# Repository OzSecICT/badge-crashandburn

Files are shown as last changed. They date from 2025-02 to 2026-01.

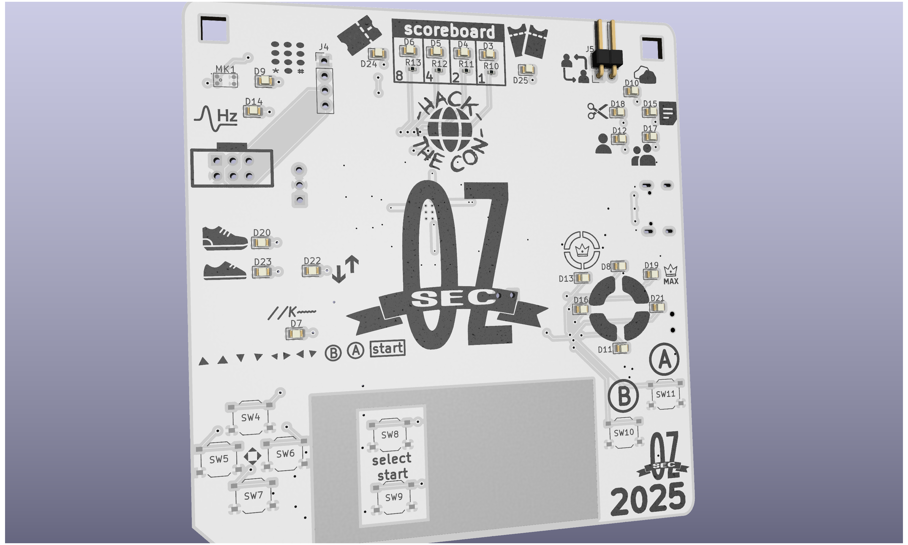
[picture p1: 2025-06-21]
hardware/kicad/OzSec2025-ESP32/images/Rendering_White.png

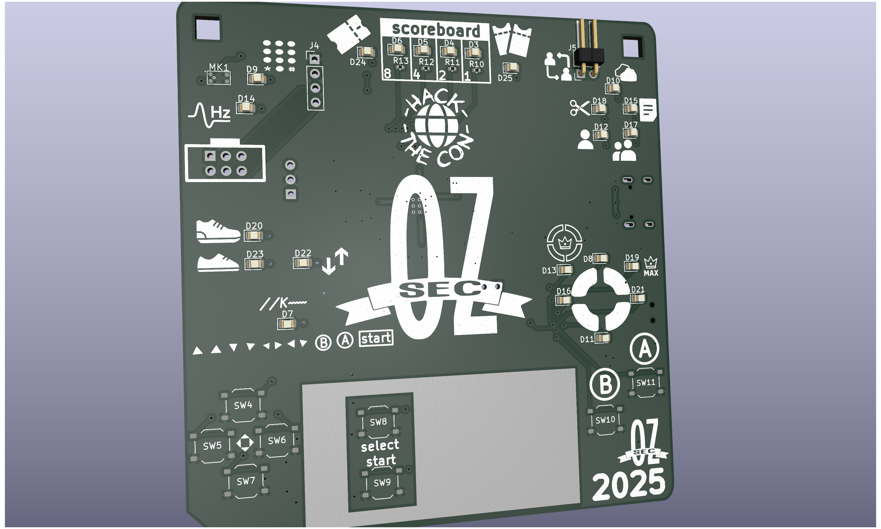
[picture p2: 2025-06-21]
hardware/kicad/OzSec2025-ESP32/images/Rendering_Green.png

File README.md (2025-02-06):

# OzSec 2025 Badge: CRASHANDBURN
This is the git repo for the code and supporting documents for the OzSec 2025 badge, codename CRASHANDBURN.

This badge will be built in MicroPython on an RP2040 or RP2350, and support multiple minigames.

This repo is currently a work in progress as we start planning how to lay out the badge firmware.

## Contributing
You will need a few things to help develop the badge firmware:
- Visual Studio Code
- VS Code Extensions: Python, Pylance
- Python 3.12+
- mpremote 1.24+

Install Python, and then install `mpremote`. Install VS Code, and clone this repository. Open the repo in VS Code and install the recommended extensions.

Currently the badge firmware is developed with a Raspberry Pi Pico 2 on a breadboard. If you want to see the code, obtain one and follow these steps to get it setup:
- Plug in drive while holding BOOTSEL and use the flash script or VS Code Task to flash firmware. 
    - In VS Code, hit Ctrl+Shift+P or Cmd+Shift+P and choose `Tasks: Run Task` followed by `Flash MicroPython Firmware`.
- After you make changes to the code, hit Ctrl+Shift+B or Cmd+Shift+B to automatically upload the code and reset the device.

## Folder Structure
`.vscode` has the needed VS Code settings for recommended plugins, tasks, and settings for Pylance.

`firmware` has the MicroPython firmware, so everyone uses the same one.

`scripts` contains supporting scripts, such as flash and upload scripts. These are used by VS Code Tasks.

`source` is the MicroPython source files uploaded to the device.

`typings` contains Python typings for MicroPython. It stops the red squigglies.

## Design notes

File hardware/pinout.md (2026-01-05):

# Pinout
Below pinout is for ESP32 version.

## LEDs
Badge Complete = GPIO2
Badge Bonus = GPIO4

Score 1s = GPIO5
Score 2s = GPIO6
Score 4s = GPIO7
Score 8s = GPIO15

RPS Complete = GPIO8
RPS Rock = GPIO16
RPS Paper = GPIO17
RPS Scissors = GPIO18

Simon Complete = GPIO46
Simon Up = GPIO3
Simon Right = GPIO9
Simon Left = GPIO11
Simon Down = GPIO10

DTMF Complete = GPIO43
DTMF Bonus = GPIO44

HiLo Complete = GPIO40
HiLo Hi = GPIO42
HiLo Lo = GPIO41

Kode Complete = GPIO39

## Buttons
Up = GPIO38
Right = GPIO47
Left = GPIO45
Down = GPIO48

Select = GPIO14
Start = GPIO21

A = GPIO12
B = GPIO13

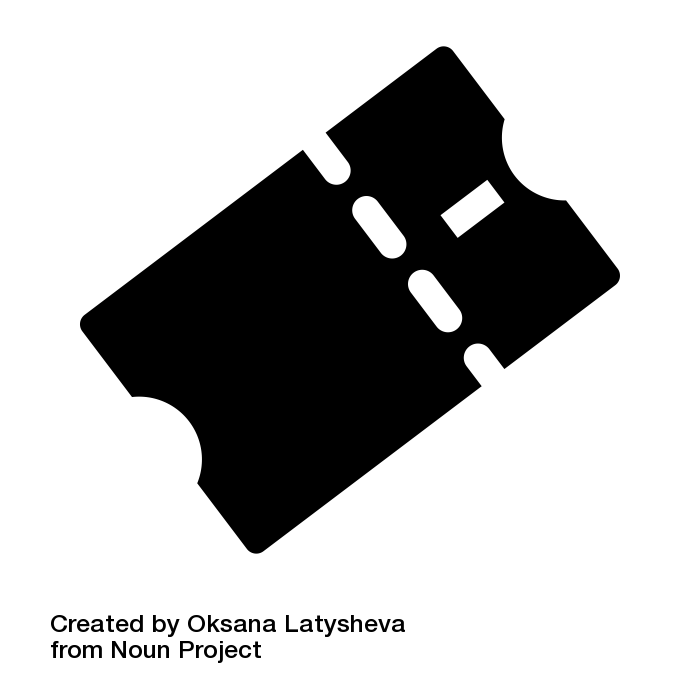
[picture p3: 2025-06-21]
hardware/kicad/OzSec2025-ESP32/images/raffle.png

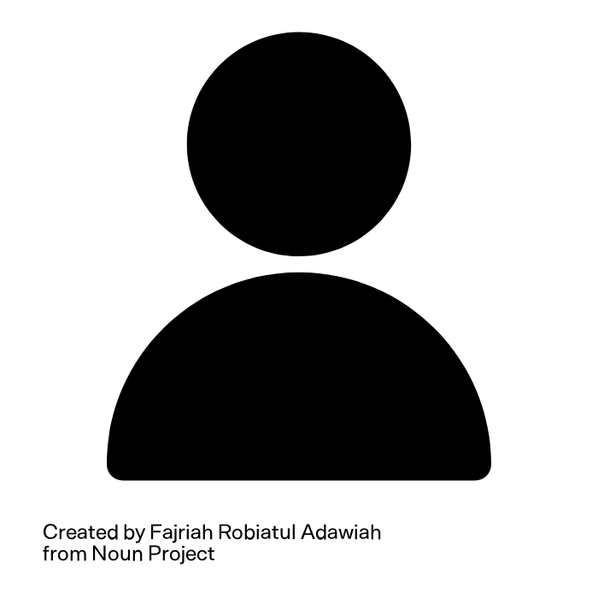
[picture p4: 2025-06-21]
hardware/kicad/OzSec2025-ESP32/images/rps-single.png

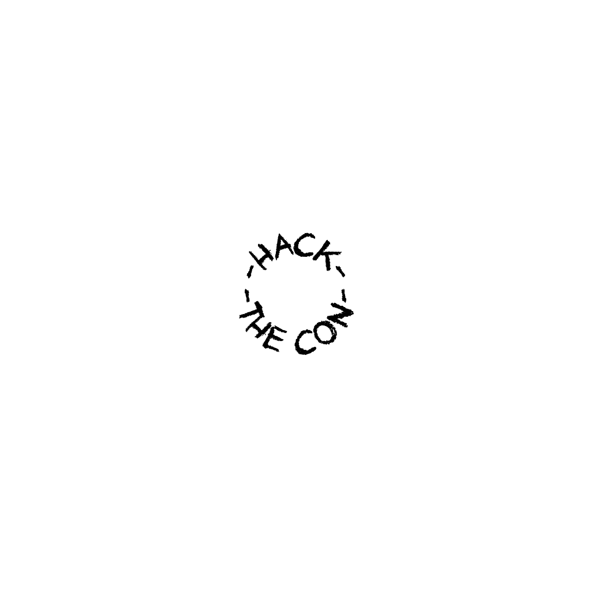
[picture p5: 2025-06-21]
hardware/kicad/OzSec2025-ESP32/images/hackthecon.png

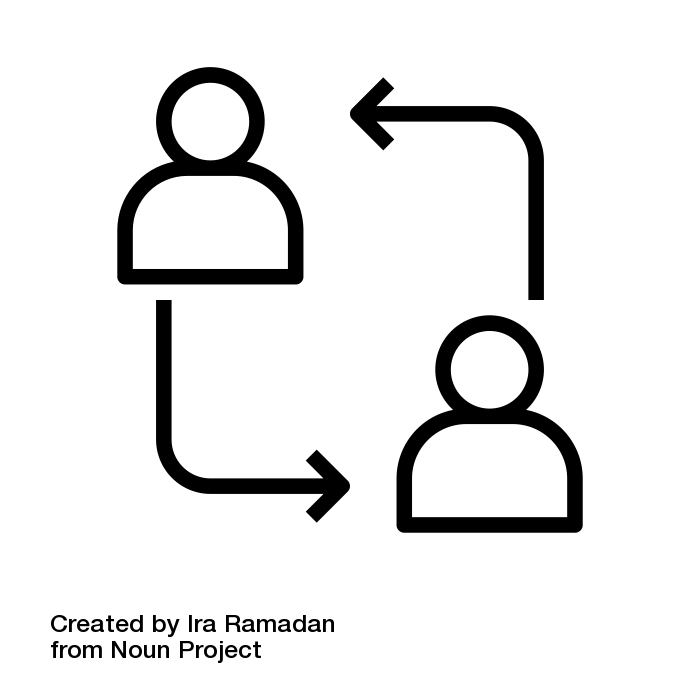
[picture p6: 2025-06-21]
hardware/kicad/OzSec2025-ESP32/images/RPS_Link.png

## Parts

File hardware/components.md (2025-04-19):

# Component Bill of Materials

This is the current planned/work in progress bill of materials.

https://jlcpcb.com/partdetail/Waveshare-1_8inch_LCDModule/C359940 - round
https://jlcpcb.com/partdetail/C42370667 / https://www.waveshare.com/1.28inch-touch-lcd.htm - new, round with touch

https://jlcpcb.com/partdetail/Hs-HS96L03W2C03/C5248080 - small square
https://jlcpcb.com/partdetail/Newvisio-N087_2832TSWYG02H14/C2890610 - small rectangle

## TODO
Update 1k resistors to 0402 like the Crystal
Update footprint of controller buttons, currently using the reset/boot buttons.
Add jtag header
add uart header
add gpio headers

## USB Connector
USB-C Connector: [C2988369](https://jlcpcb.com/partdetail/gswitch-GT_USB7010ASV/C2988369)
ESD Protection: [C2827654](https://jlcpcb.com/partdetail/TechPublic-USBLC62SC6/C2827654)
USB-C 5.1k resistors x2: [C27834](https://jlcpcb.com/partdetail/26648-0402WGF5101TCE/C25905)

## Charge Controller
Controller: C478383
Capacitor 1uF: C52923
Resistors 2k x2: C17604
Fuse: C261957
Power Switch: C431541
AA Connectors x2: C2979179
Charge LED Yellow: C2296

## Voltage Regulator
Regulator: C15578
Capcitor 1uF: C1525
Capcitor 100uF: C15008
LED resistor 1k: C17513
LED green: C2297

## RP Crystal
Crystal: C20625731 $0.1980
Resistor 1k: C17513 $0.0017
Capacitor 15pF 2x: C1644 $0.0045

## RP Flash
Chip: C97521 $0.3375
Capacitor 100nF: C1525 $0.0010
Resistor 0ohm: C17168 $0.0005

## RP2350
Chip: C42415655 $1.1760
Resistor 27ohm x2: C138021 $0.0006
Reset and boot switches: C318884 $0.0146
resistor 33ohm: C25105 $0.0005
resistor 1k x2: C17513 $0.0017
capacitor 100nF x11: C307331 $0.0052
capacitor 4.7uF x4: C23733 $0.0050
Inductor: C42411119 $0.1967

ESP32-S3-WROOM-1-N8R8: $3.92
RP2350 and friends: $1.82
CH32V003F4U6: $0.1863

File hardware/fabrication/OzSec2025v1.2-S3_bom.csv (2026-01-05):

Designator | Footprint | Quantity | Value | LCSC Part #
BATTERY | MY-AA-04_Silkscreen_Only | 1 | Battery | C2979179
BT1 | MY-AA-04 | 1 | Battery_Clip_+ | C2979179
BT3 | MY-AA-04 | 1 | Battery_Clip_- | C2979179
C1 | 0805 | 1 | 22uF | C45783
C2, C4 | 0805 | 2 | 100nF | C49678
C3 | 0805 | 1 | 10uF | C15850
C5 | 1206 | 1 | 100uF | C15008
C6 | 0805 | 1 | 1uF | C28323
D1, D13, D19, D6 | 0805 | 4 | GREEN | C2297
D10, D11, D12, D14, D15, D16, D17, D18, D2, D3, D4, D5, D7, D8, D9 | 0805 | 15 | WHITE | C34499
D20, D23 | 0805 | 2 | YELLOW | C2296
D21 | 0805 | 1 | RED | C84256
D22 | 0805 | 1 | BLUE | C2293
F1 | 1206 | 1 | Fuse | C261957
J1 | USB_C_Receptacle_G-Switch_GT-USB-7010ASV | 1 | USB_C_Receptacle_USB2.0 | C2988369
MK1 | LMA3722T421-OA5 | 1 | LMA3722T421-OA5 | C5373233
R1, R10, R12, R13, R14, R15, R16, R17, R18, R19, R2, R20, R21, R22, R23, R24, R25, R26, R3, R4, R5, R6, R9 | 0805 | 23 | 1K | C17513
R11 | 0805 | 1 | 10K | C17414
R27 | 0805 | 1 | 2K | C17604
R7, R8 | 0805 | 2 | 5.1K | C27834
SW1 | SW_SPDT_PCM12 | 1 | SPDT | C431541
SW10, SW11, SW2, SW3, SW4, SW5, SW6, SW7, SW8, SW9 | SW_Push_1P1T_XKB_TS-1187A | 10 | SW_Push | C318884
U1 | SOT-23-6 | 1 | USBLC6-2SC6 | C2827654
U2 | SOT-223-3_TabPin2 | 1 | TLV1117LV-33 | C15578
U3 | ESP32-S3-WROOM-1 | 1 | ESP32-S3-WROOM-1-N8R8 | C2913201
U4 | TSOT-23-5 | 1 | ME4054BM5G-N | C478383
X1 | Simple_Addon_v2-BADGE-2x3 | 1 | Simple_Addon_v2 | C2935983

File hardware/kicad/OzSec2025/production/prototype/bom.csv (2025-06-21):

Designator | Footprint | Quantity | Value | LCSC Part #
BT1 | MY-AA-04_BT1A | 1 | Battery_Clip_+
BT2 | MY-AA-04 | 1 | Battery | C2979179
BT3 | MY-AA-04_BT1B | 1 | Battery_Clip_-
C1, C12, C13, C14, C15, C16, C17, C18, C19, C20, C21, C22, C9 | 0402 | 13 | 100n | C1525
C10, C11, C7, C8 | 0402 | 4 | 4.7u | C23733
C2, C3 | 0402 | 2 | 15p | C1548
C4 | 0805 | 1 | 10u | C15850
C5 | 1206 | 1 | 100uF | C15008
C6 | 0402 | 1 | 1uF | C52923
D1 | 0805 | 1 | YELLOW | C2296
D10, D11, D12, D13, D14, D15, D16, D17, D18, D19, D20, D21, D22, D23, D24, D25, D3, D4, D5, D6, D7, D8, D9 | 0805 | 23 | WHITE | C34499
D2 | 0805 | 1 | GREEN | C2297
F1 | 1206 | 1 | Fuse | C261957
J1 | USB_C_Receptacle_G-Switch_GT-USB-7010ASV | 1 | USB_C_Receptacle_USB2.0 | C2988369
J5 | PinHeader_1x02_P2.54mm_Horizontal | 1 | Conn_01x02 | C492410
L1 | L_pol_2016 | 1 | 3.3u | C42411119
MK1 | LMA3722T421-OA5 | 1 | LMA3722T421-OA5 | C5373233
R1 | 0402 | 1 | 2K | C4109
R10, R11, R12, R13, R16, R17, R18, R19, R2, R20, R21, R22, R23, R24, R25, R26, R27, R28, R29, R3, R30, R31, R32, R33, R34, R4, R7, R9 | 0402 | 28 | 1K | C11702
R14, R15 | 0402 | 2 | 27 | C25100
R5, R6 | 0402 | 2 | 5.1K | C25905
R8 | 0402 | 1 | 33 | C25105
SW1 | SW_SPDT_PCM12 | 1 | POWER | C431541
SW10, SW11, SW2, SW3, SW4, SW5, SW6, SW7, SW8, SW9 | SW_Push_1P1T_XKB_TS-1187A | 10 | SW_Push | C318884
TP1, TP3 | TestPoint_Pad_1.5x1.5mm | 2 | TestPoint
TP2, TP4 | TestPoint_Pad_D1.5mm | 2 | TestPoint
U1 | SOT-223-3_TabPin2 | 1 | TLV1117LV-33 | C15578
U2 | SOT-23-6 | 1 | USBLC6-2SC6 | C2827654
U3 | TSOT-23-5 | 1 | ME4054BM5G-N | C478383
U4 | RP2350-QFN-80-1EP_10x10_P0.4mm_EP3.4x3.4mm_ThermalVias | 1 | RP2350_80QFN | C42415655
U5 | SOIC-8_5.23x5.23mm_P1.27mm | 1 | W25Q128JVS | C97521
X1 | Simple_Addon_v2-BADGE-2x3 | 1 | Simple_Addon_v2 | C2935983
Y1 | Crystal_SMD_3225-4Pin_3.2x2.5mm | 1 | ABM8-272-T3 | C20625731

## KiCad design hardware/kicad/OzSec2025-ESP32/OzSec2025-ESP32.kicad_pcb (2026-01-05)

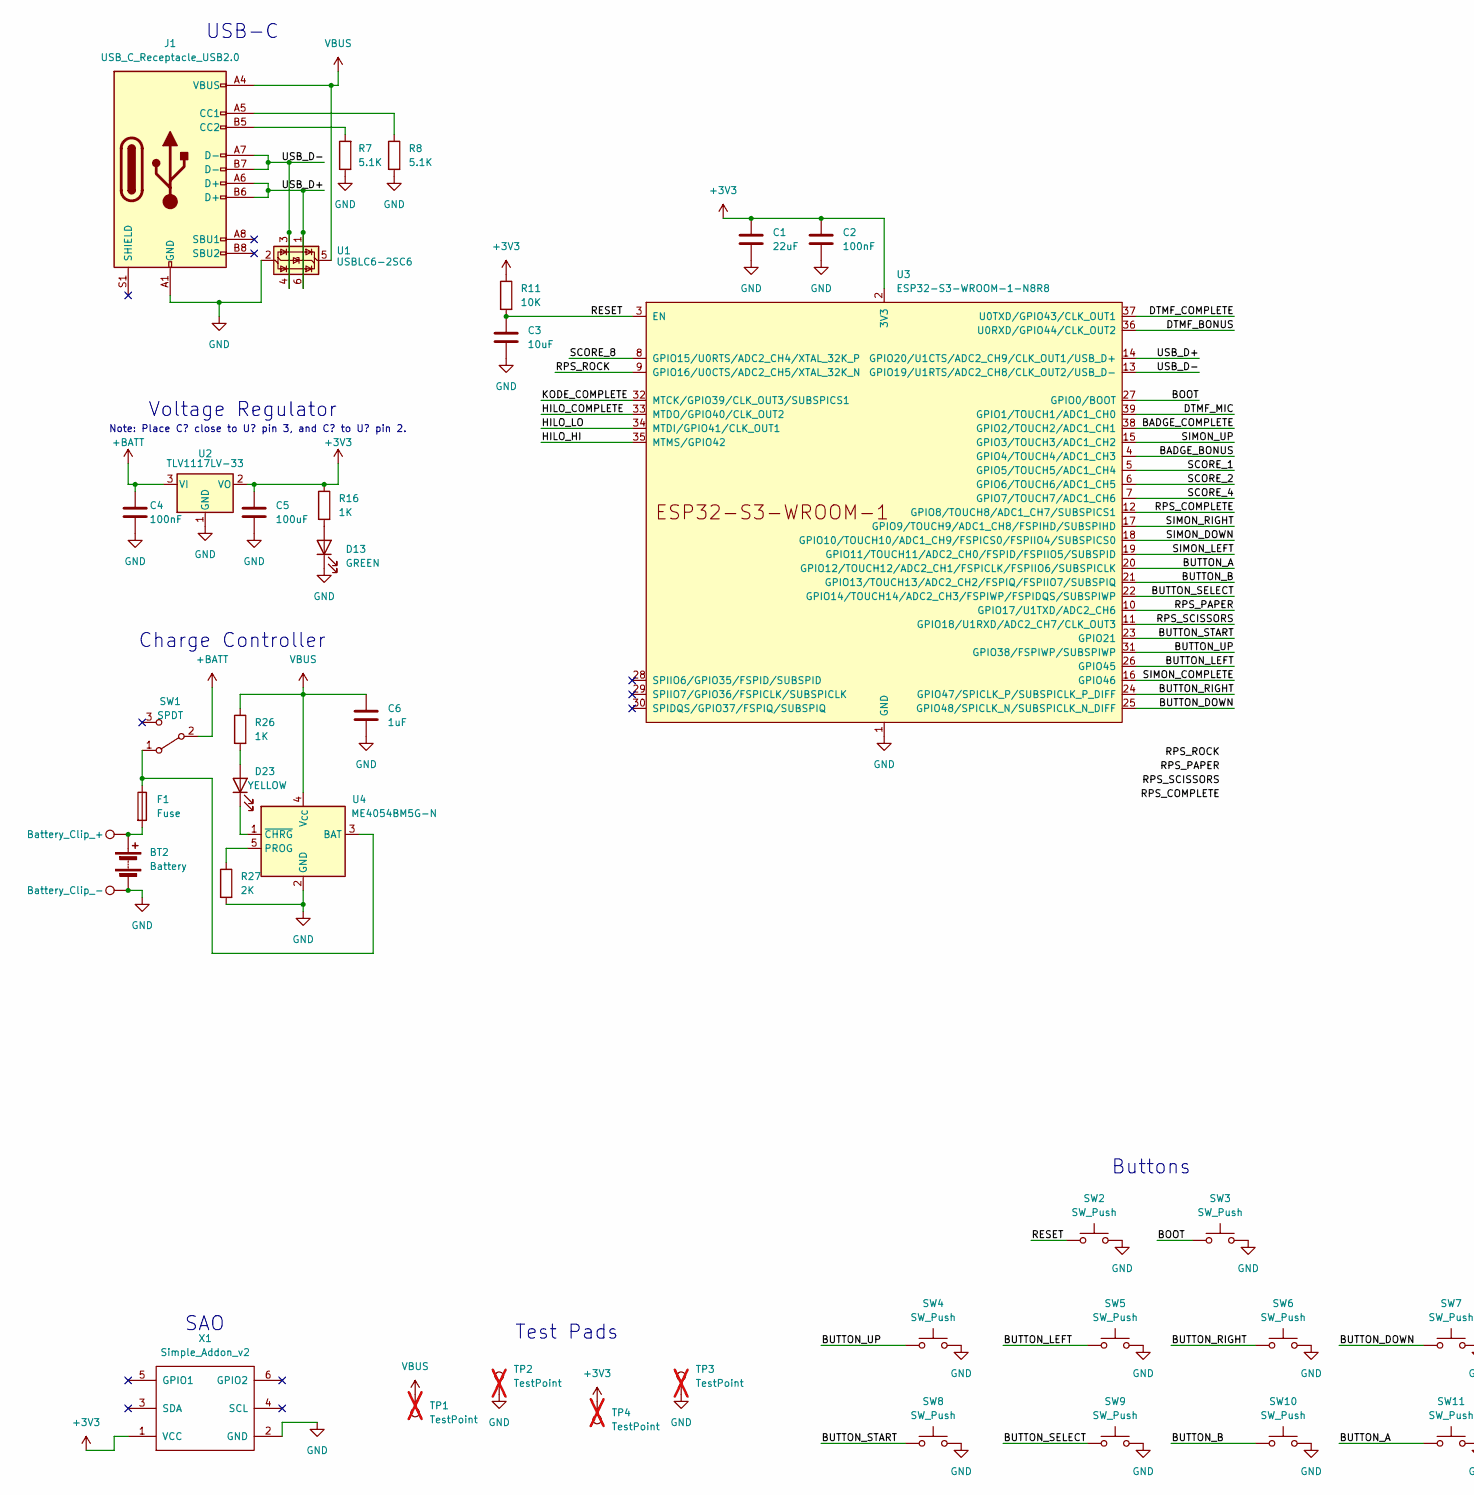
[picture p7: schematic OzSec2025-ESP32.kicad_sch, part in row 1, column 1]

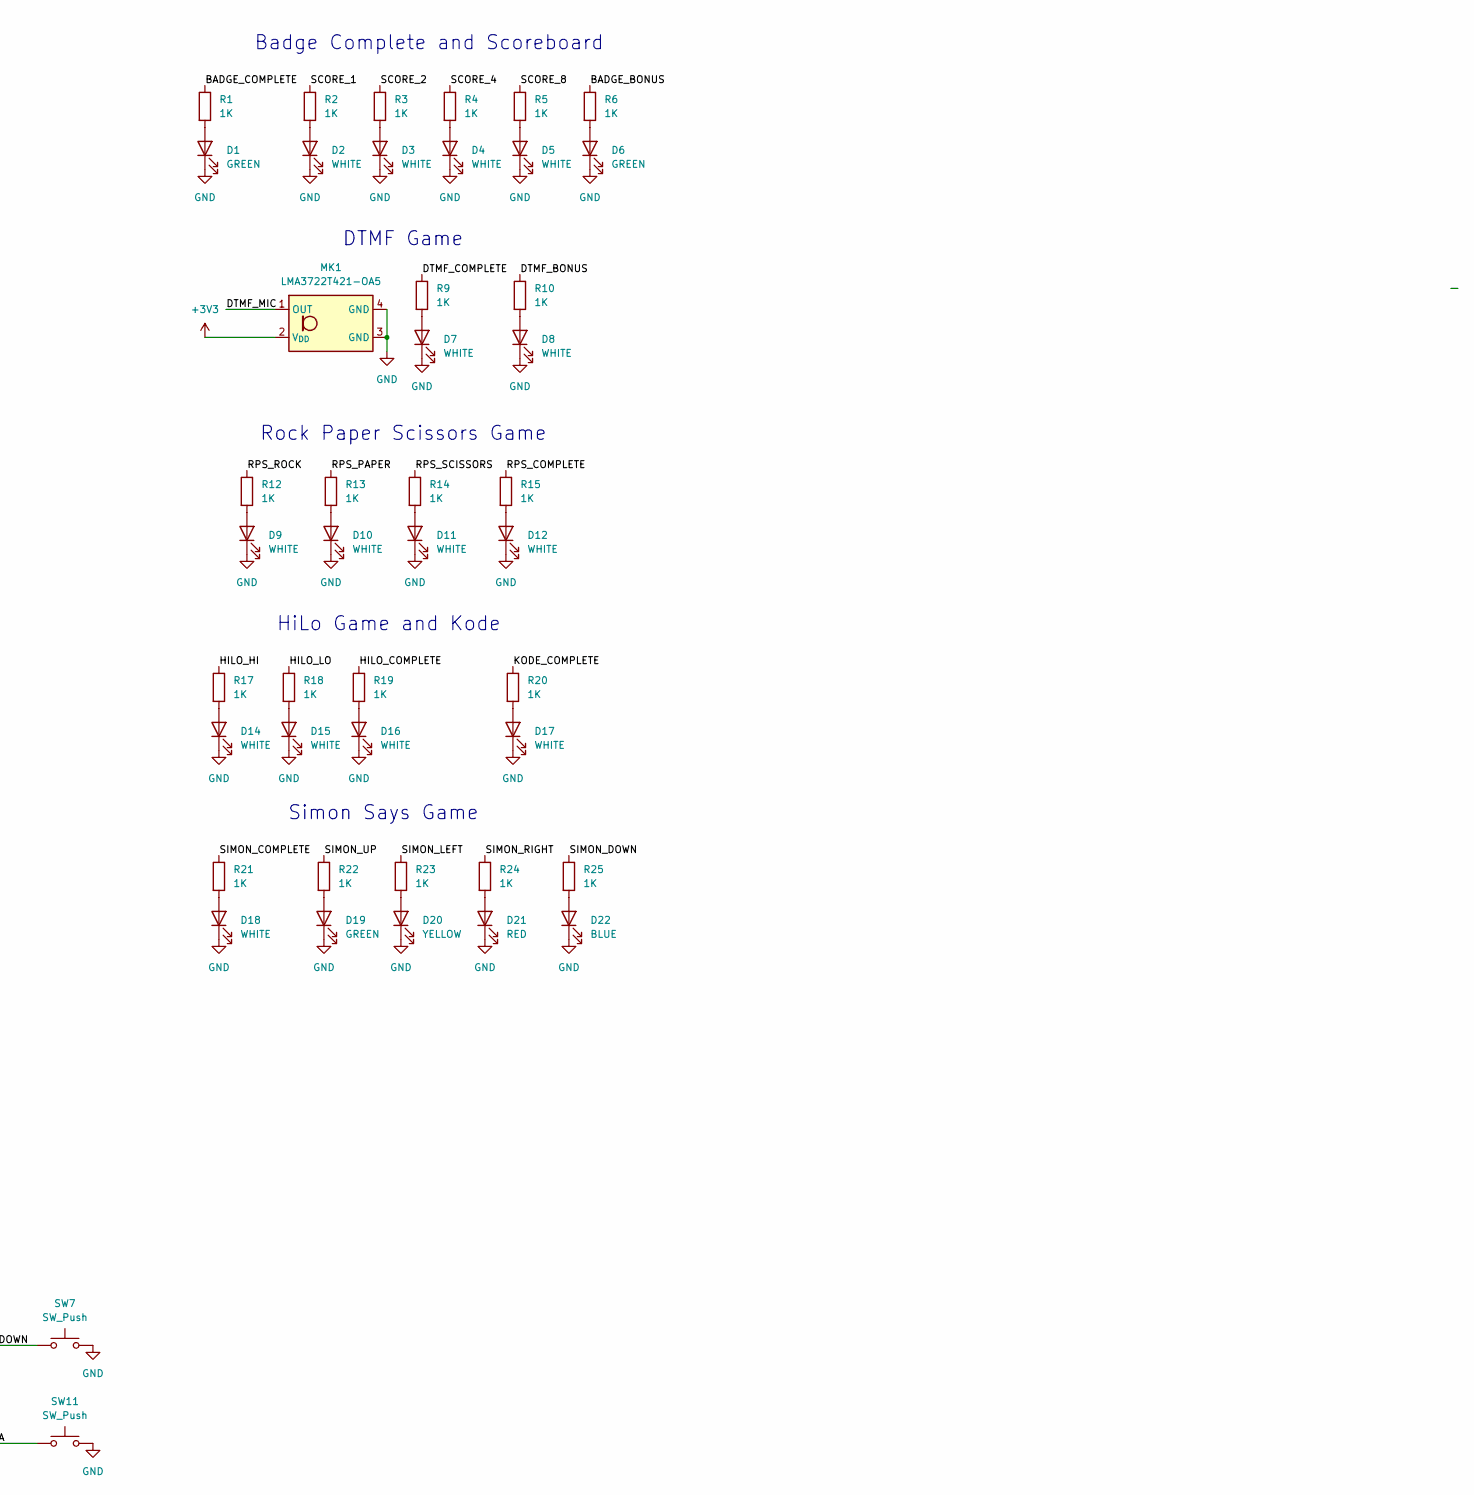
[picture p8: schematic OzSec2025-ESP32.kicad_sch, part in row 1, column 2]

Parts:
BT1: Battery_Clip_+; MY-AA-04; LCSC C2979179
BT2: Battery; MY-AA-04; LCSC C2979179
BT3: Battery_Clip_-; MY-AA-04; LCSC C2979179
C1: 22uF; C_0805_2012Metric_Pad1.18x1.45mm_HandSolder; LCSC C45783
C2, C4: 100nF; C_0805_2012Metric_Pad1.18x1.45mm_HandSolder; LCSC C49678
C3: 10uF; C_0805_2012Metric_Pad1.18x1.45mm_HandSolder; LCSC C15850
C5: 100uF; C_1206_3216Metric_Pad1.33x1.80mm_HandSolder; LCSC C15008
C6: 1uF; C_0805_2012Metric_Pad1.18x1.45mm_HandSolder; LCSC C28323
D1, D6, D13, D19: GREEN; LED_0805_2012Metric_Pad1.15x1.40mm_HandSolder; LCSC C2297
D2, D3, D4, D5, D7, D8, D9, D10, D11, D12, D14, D15, D16, D17, D18: WHITE; LED_0805_2012Metric_Pad1.15x1.40mm_HandSolder; LCSC C34499
D20, D23: YELLOW; LED_0805_2012Metric_Pad1.15x1.40mm_HandSolder; LCSC C2296
D21: RED; LED_0805_2012Metric_Pad1.15x1.40mm_HandSolder; LCSC C84256
D22: BLUE; LED_0805_2012Metric_Pad1.15x1.40mm_HandSolder; LCSC C2293
F1: Fuse; Fuse_1206_3216Metric_Pad1.42x1.75mm_HandSolder; LCSC C261957
J1: USB_C_Receptacle_USB2.0; USB_C_Receptacle_G-Switch_GT-USB-7010ASV; LCSC C2988369
MK1: LMA3722T421-OA5; LCSC C5373233
R1, R2, R3, R4, R5, R6, R9, R10, R12, R13, R14, R15, R16, R17, R18, R19, R20, R21, R22, R23, R24, R25, R26: 1K; R_0805_2012Metric_Pad1.20x1.40mm_HandSolder; LCSC C17513
R7, R8: 5.1K; R_0805_2012Metric_Pad1.20x1.40mm_HandSolder; LCSC C27834
R11: 10K; R_0805_2012Metric_Pad1.20x1.40mm_HandSolder; LCSC C17414
R27: 2K; R_0805_2012Metric_Pad1.20x1.40mm_HandSolder; LCSC C17604
SW1: SPDT; SW_SPDT_PCM12; LCSC C431541
SW2, SW3, SW4, SW5, SW6, SW7, SW8, SW9, SW10, SW11: SW_Push; SW_Push_1P1T_XKB_TS-1187A; LCSC C318884
TP1, TP4: TestPoint; TestPoint_Pad_1.5x1.5mm; not fitted
TP2, TP3: TestPoint; TestPoint_Pad_D1.5mm; not fitted
U1: USBLC6-2SC6; SOT-23-6; LCSC C2827654
U2: TLV1117LV-33; SOT-223-3_TabPin2; LCSC C15578
U3: ESP32-S3-WROOM-1-N8R8; ESP32-S3-WROOM-1; LCSC C2913201
U4: ME4054BM5G-N; TSOT-23-5; LCSC C478383
X1: Simple_Addon_v2; Simple_Addon_v2-BADGE-2x3; LCSC C2935983

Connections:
+3V3: C1.1, C2.1, C5.1, MK1.2 (V_{DD}), R11.1, R16.1, TP4.1, U2.2 (VO), U3.2 (3V3), X1.1 (VCC)
+BATT: C4.1, SW1.2 (B), U2.3 (VI)
/BADGE_BONUS: R6.1, U3.4 (GPIO4/TOUCH4/ADC1_CH3)
/BADGE_COMPLETE: R1.1, U3.38 (GPIO2/TOUCH2/ADC1_CH1)
/BOOT: SW3.1, U3.27 (GPIO0/BOOT)
/BUTTON_A: SW11.1, U3.20 (GPIO12/TOUCH12/ADC2_CH1/FSPICLK/FSPIIO6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)
/BUTTON_B: SW10.1, U3.21 (GPIO13/TOUCH13/ADC2_CH2/FSPIQ/FSPIIO7/S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)
/BUTTON_DOWN: SW7.1, U3.25 (GPIO48/SPICLK_N/SUBSPICLK_N_DIFF)
/BUTTON_LEFT: SW5.1, U3.26 (GPIO45)
/BUTTON_RIGHT: SW6.1, U3.24 (GPIO47/SPICLK_P/SUBSPICLK_P_DIFF)
/BUTTON_SELECT: SW9.1, U3.22 (GPIO14/TOUCH14/ADC2_CH3/FSPIWP/FSPIDQS/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)
/BUTTON_START: SW8.1, U3.23 (GPIO21)
/BUTTON_UP: SW4.1, U3.31 (GPIO38/FSPIWP/SUBSPIWP)
/DTMF_BONUS: R10.1, U3.36 (U0RXD/GPIO44/CLK_OUT2)
/DTMF_COMPLETE: R9.1, U3.37 (U0TXD/GPIO43/CLK_OUT1)
/DTMF_MIC: MK1.1 (OUT), U3.39 (GPIO1/TOUCH1/ADC1_CH0)
/HILO_COMPLETE: R19.1, U3.33 (MTDO/GPIO40/CLK_OUT2)
/HILO_HI: R17.1, U3.35 (MTMS/GPIO42)
/HILO_LO: R18.1, U3.34 (MTDI/GPIO41/CLK_OUT1)
/KODE_COMPLETE: R20.1, U3.32 (MTCK/GPIO39/CLK_OUT3/SUBSPICS1)
/RESET: C3.1, R11.2, SW2.1, U3.3 (EN)
/RPS_COMPLETE: R15.1, U3.12 (GPIO8/TOUCH8/ADC1_CH7/SUBSPICS1)
/RPS_PAPER: R13.1, U3.10 (GPIO17/U1TXD/ADC2_CH6)
/RPS_ROCK: R12.1, U3.9 (GPIO16/U0CTS/ADC2_CH5/XTAL_32K_N)
/RPS_SCISSORS: R14.1, U3.11 (GPIO18/U1RXD/ADC2_CH7/CLK_OUT3)
/SCORE_1: R2.1, U3.5 (GPIO5/TOUCH5/ADC1_CH4)
/SCORE_2: R3.1, U3.6 (GPIO6/TOUCH6/ADC1_CH5)
/SCORE_4: R4.1, U3.7 (GPIO7/TOUCH7/ADC1_CH6)
/SCORE_8: R5.1, U3.8 (GPIO15/U0RTS/ADC2_CH4/XTAL_32K_P)
/SIMON_COMPLETE: R21.1, U3.16 (GPIO46)
/SIMON_DOWN: R25.1, U3.18 (GPIO10/TOUCH10/ADC1_CH9/FSPICS0/FSPIIO4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)
/SIMON_LEFT: R23.1, U3.19 (GPIO11/TOUCH11/ADC2_CH0/FSPID/FSPIIO5/S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)
/SIMON_RIGHT: R24.1, U3.17 (GPIO9/TOUCH9/ADC1_CH8/FSPIHD/SUBSPIHD)
/SIMON_UP: R22.1, U3.15 (GPIO3/TOUCH3/ADC1_CH2)
/USB_D+: J1.A6 (D+), J1.B6 (D+), U1.1 (I/O1), U1.6 (I/O1), U3.14 (GPIO20/U1CTS/ADC2_CH9/CLK_OUT1/USB_D+)
/USB_D-: J1.A7 (D-), J1.B7 (D-), U1.3 (I/O2), U1.4 (I/O2), U3.13 (GPIO19/U1RTS/ADC2_CH8/CLK_OUT2/USB_D-)
GND: BT1.2, BT3.1, C1.2, C2.2, C3.2, C4.2, C5.2, C6.2, D1.1 (K), D2.1 (K), D3.1 (K), D4.1 (K), D5.1 (K), D6.1 (K), D7.1 (K), D8.1 (K), D9.1 (K), D10.1 (K), D11.1 (K), D12.1 (K), D13.1 (K), D14.1 (K), D15.1 (K), D16.1 (K), D17.1 (K), D18.1 (K), D19.1 (K), D20.1 (K), D21.1 (K), D22.1 (K), J1.A1 (GND), J1.A12 (GND), J1.B1 (GND), J1.B12 (GND), MK1.3 (GND), MK1.4 (GND), R7.1, R8.2, R27.2, SW2.2, SW3.2, SW4.2, SW5.2, SW6.2, SW7.2, SW8.2, SW9.2, SW10.2, SW11.2, TP2.1, TP3.1, U1.2 (GND), U2.1 (GND), U3.1 (GND), U3.40 (GND), U3.41 (GND), U4.2 (GND), X1.2 (GND)
unnamed: BT1.1, F1.2
unnamed: D1.2 (A), R1.2
unnamed: D2.2 (A), R2.2
unnamed: D3.2 (A), R3.2
unnamed: D4.2 (A), R4.2
unnamed: D5.2 (A), R5.2
unnamed: D6.2 (A), R6.2
unnamed: D7.2 (A), R9.2
unnamed: D8.2 (A), R10.2
unnamed: D9.2 (A), R12.2
unnamed: D10.2 (A), R13.2
unnamed: D11.2 (A), R14.2
unnamed: D12.2 (A), R15.2
unnamed: D13.2 (A), R16.2
unnamed: D14.2 (A), R17.2
unnamed: D15.2 (A), R18.2
unnamed: D16.2 (A), R19.2
unnamed: D17.2 (A), R20.2
unnamed: D18.2 (A), R21.2
unnamed: D19.2 (A), R22.2
unnamed: D20.2 (A), R23.2
unnamed: D21.2 (A), R24.2
unnamed: D22.2 (A), R25.2
unnamed: D23.2 (A), R26.2
unnamed: D23.1 (K), U4.1 (~CHRG)
unnamed: J1.A5 (CC1), R8.1
unnamed: J1.B5 (CC2), R7.2
unnamed: F1.1, SW1.1 (A), U4.3 (BAT)
unnamed: R27.1, U4.5 (PROG)
VBUS: C6.1, J1.A4 (VBUS), J1.A9 (VBUS), J1.B4 (VBUS), J1.B9 (VBUS), R26.1, TP1.1, U1.5 (VBUS), U4.4 (V_{CC})

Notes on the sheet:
USB-C
Charge Controller
Badge Complete and Scoreboard
Test Pads
DTMF Game
Voltage Regulator
SAO
HiLo Game and Kode
Note: Place C? close to U? pin 3, and C? to U? pin 2.
Buttons
Simon Says Game
Rock Paper Scissors Game

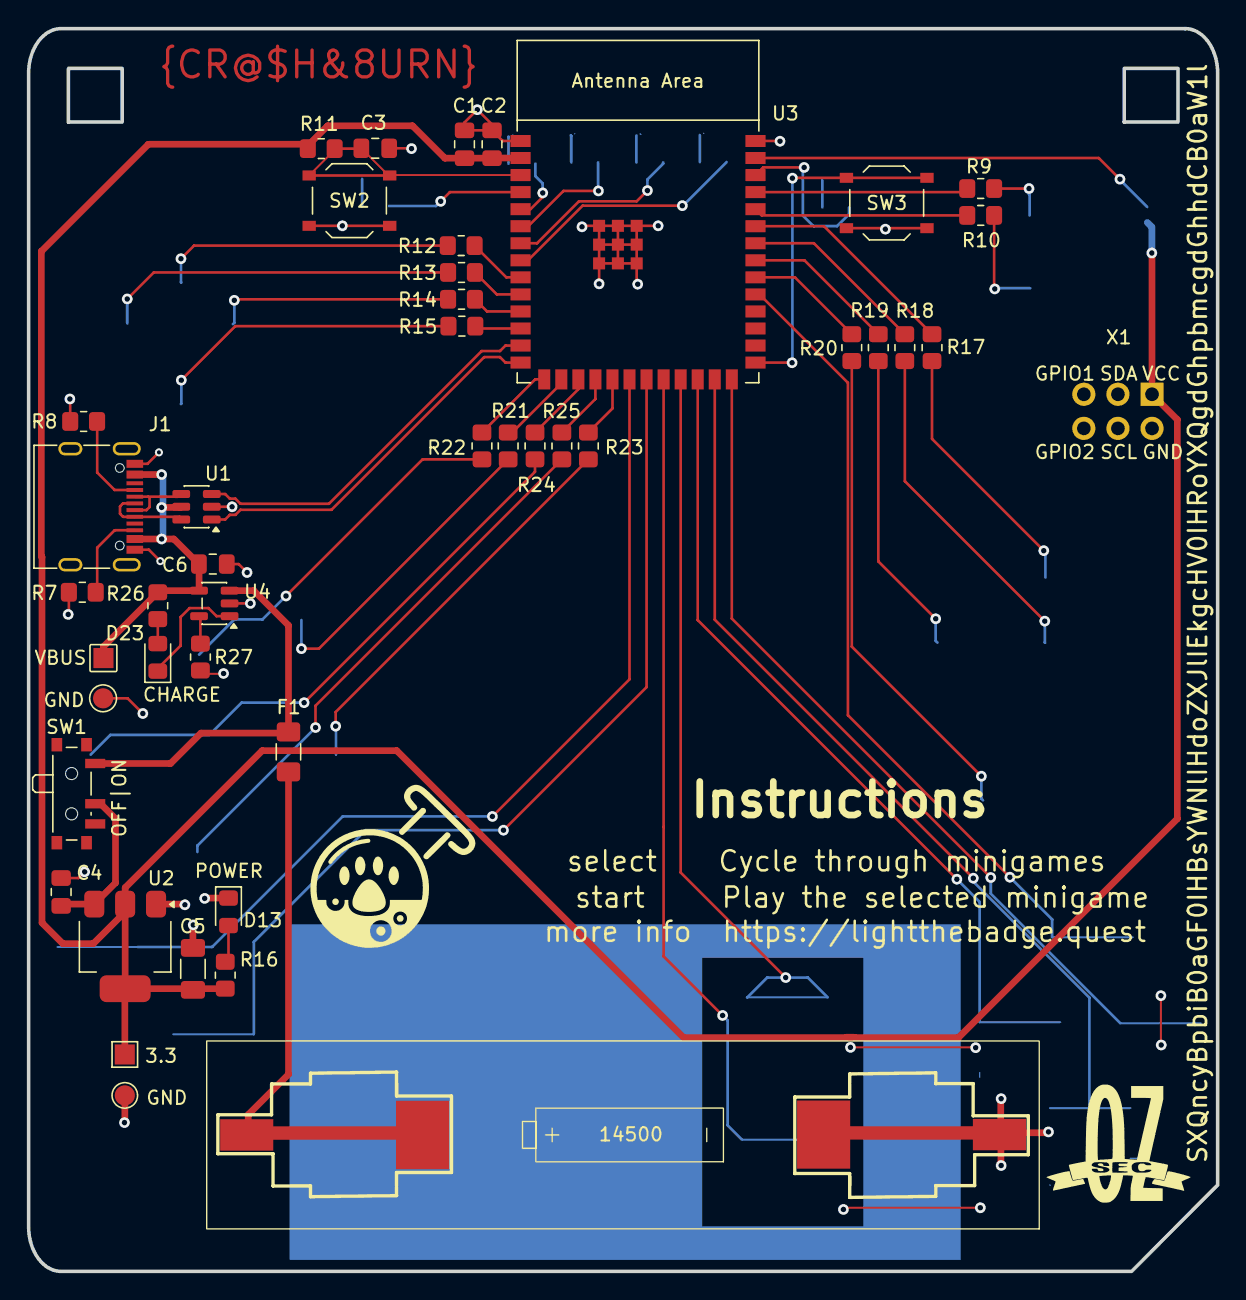
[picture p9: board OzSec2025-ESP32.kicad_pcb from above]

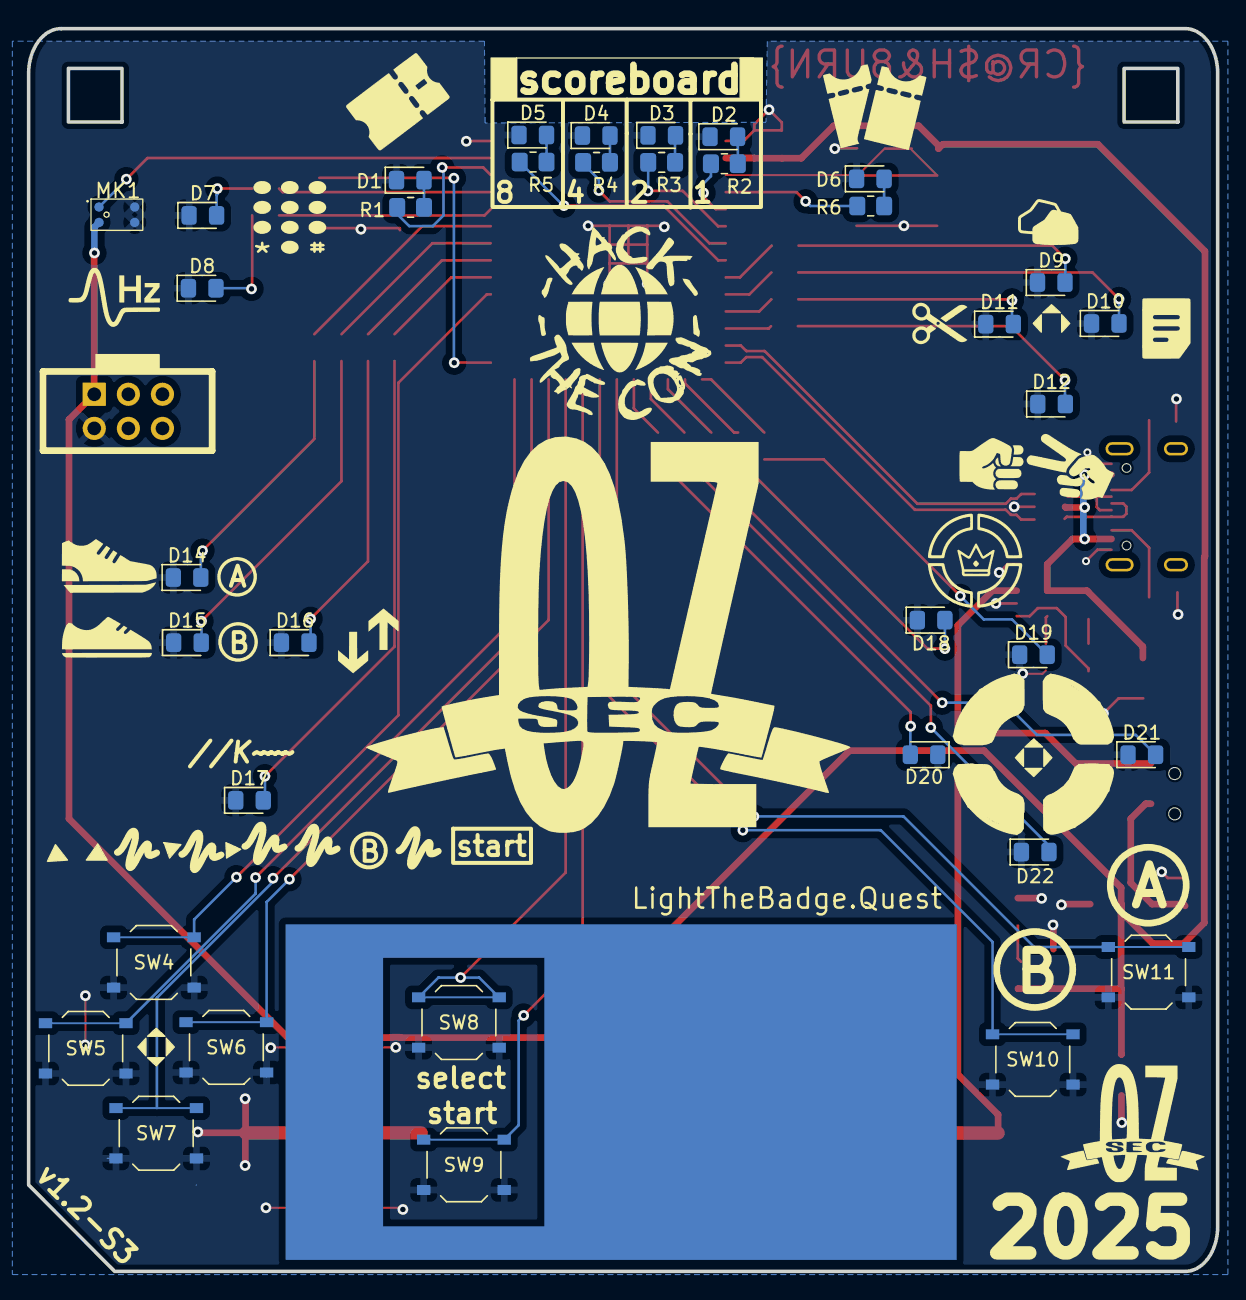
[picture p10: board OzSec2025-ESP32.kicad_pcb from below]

Board: 2 copper layers, 88.6 x 92.6 mm, 82 parts (37 on the bottom side), 67 nets.

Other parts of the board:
BATTERY: Battery; MY-AA-04_Silkscreen_Only

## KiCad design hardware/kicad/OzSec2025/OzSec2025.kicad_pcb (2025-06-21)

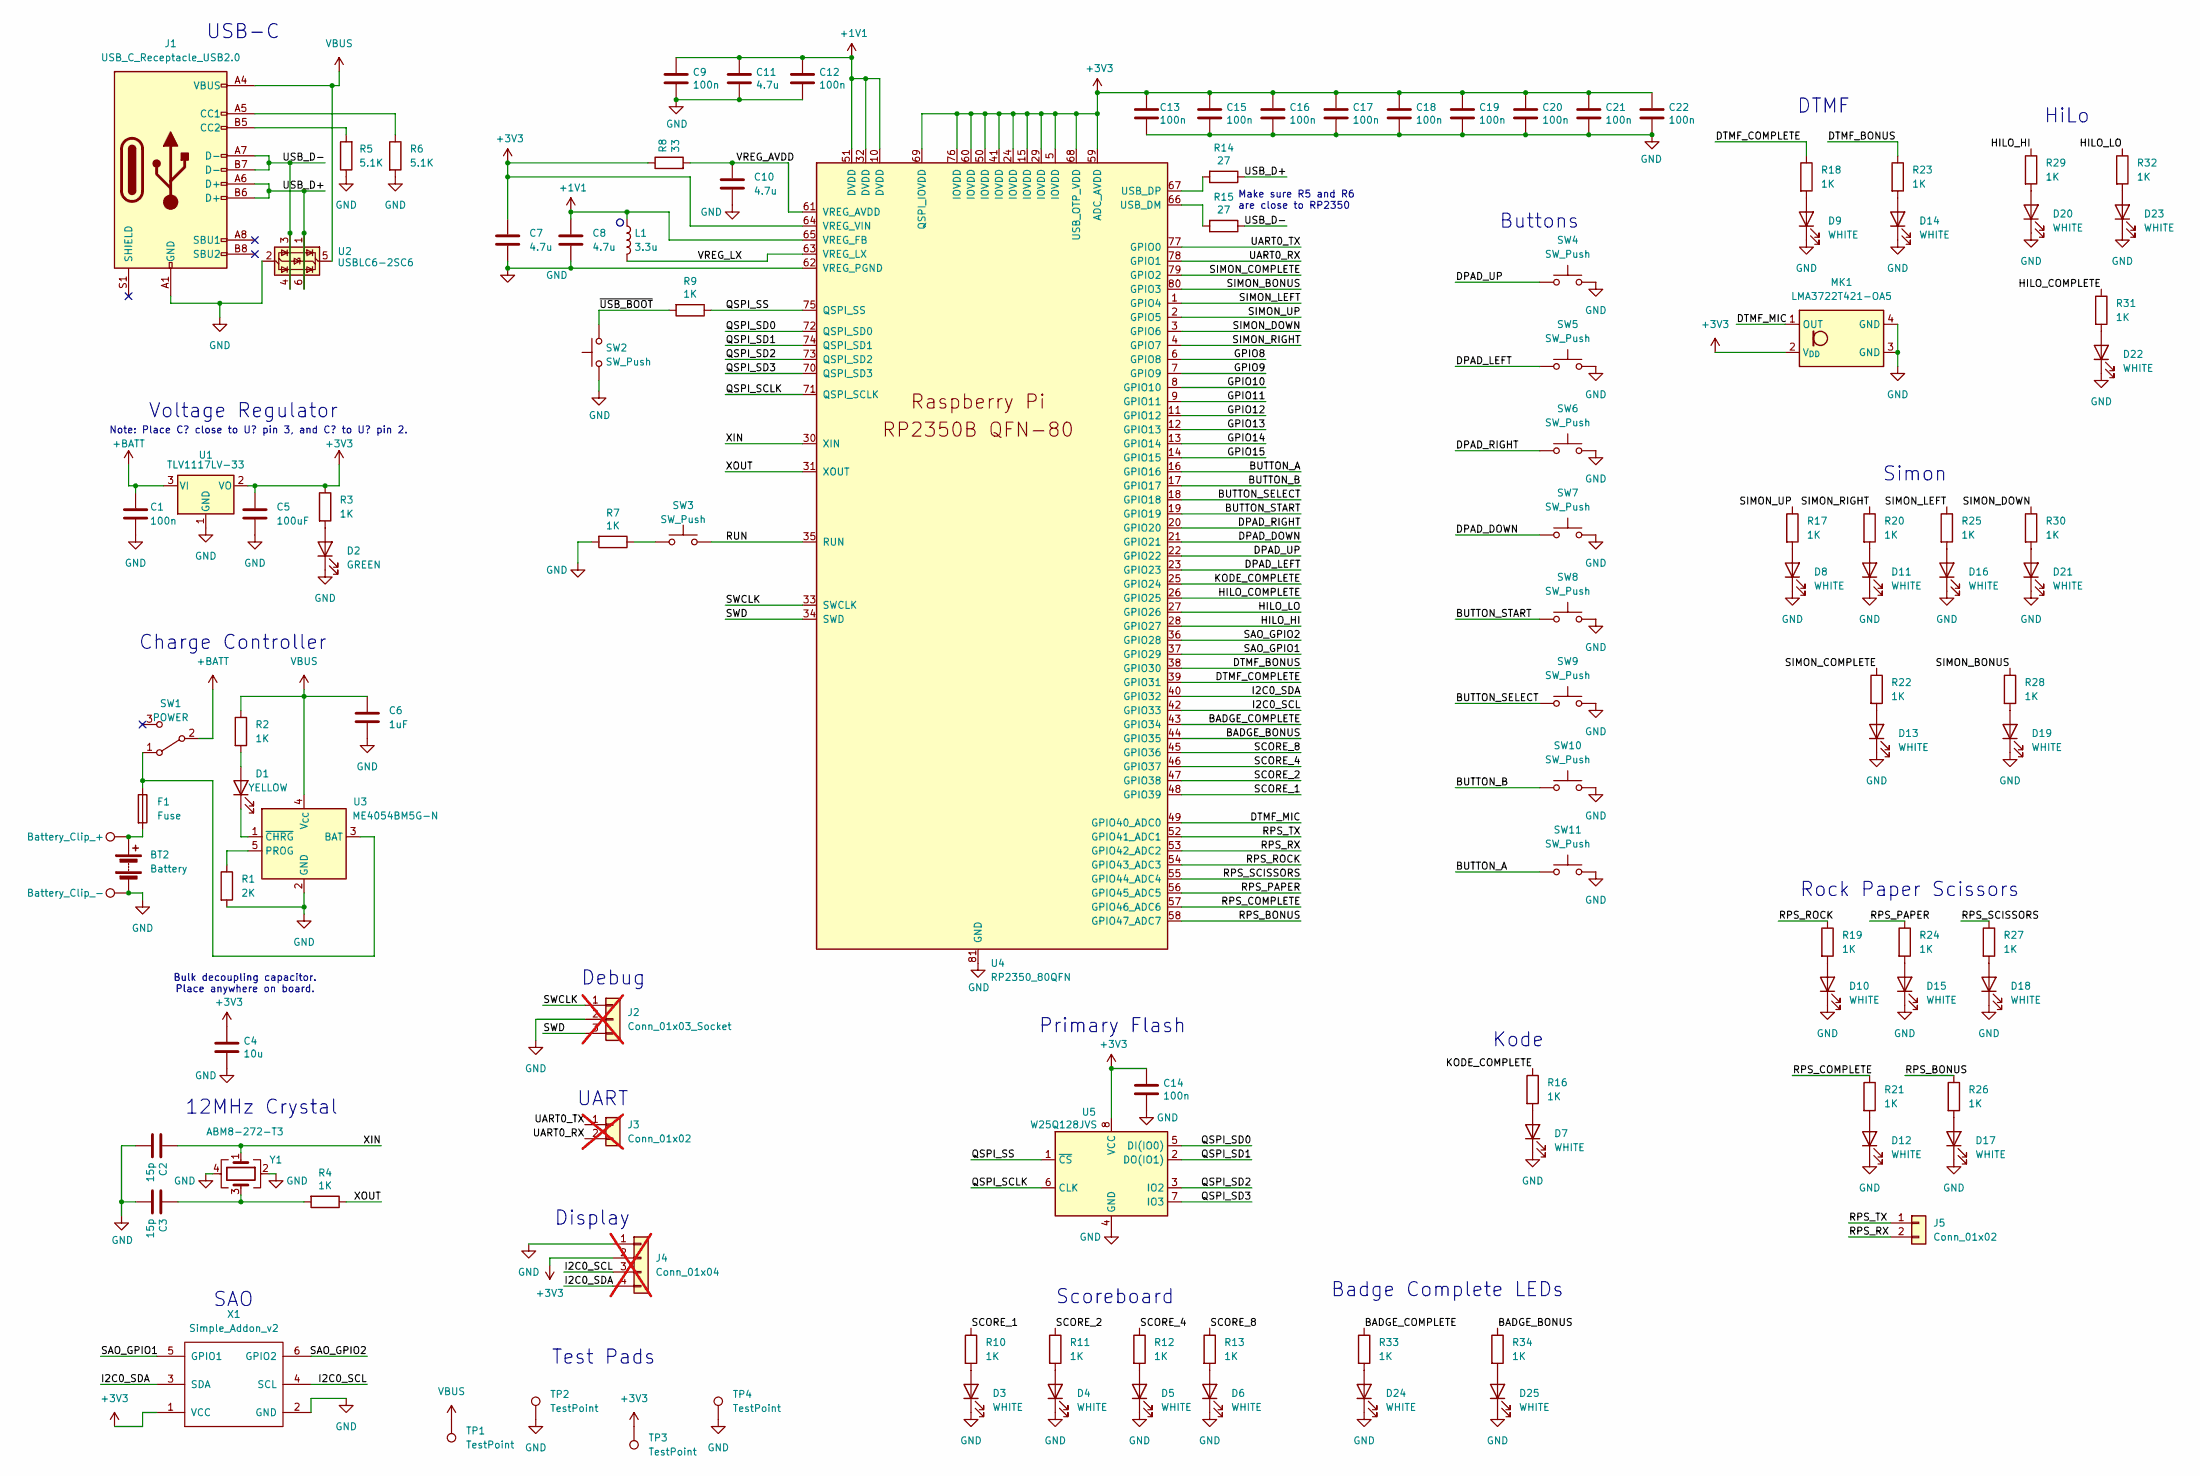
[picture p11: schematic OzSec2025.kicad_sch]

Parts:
BT1: Battery_Clip_+; MY-AA-04_BT1A
BT2: Battery; MY-AA-04; LCSC C2979179
BT3: Battery_Clip_-; MY-AA-04_BT1B
C1, C9, C12, C13, C14, C15, C16, C17, C18, C19, C20, C21, C22: 100n; C_0402_1005Metric; LCSC C1525
C2, C3: 15p; C_0402_1005Metric; LCSC C1548
C4: 10u; C_0805_2012Metric; LCSC C15850
C5: 100uF; C_1206_3216Metric; LCSC C15008
C6: 1uF; C_0402_1005Metric; LCSC C52923
C7, C8: 4.7u; C_0402_1005Metric_small_pads; LCSC C23733
C10, C11: 4.7u; C_0402_1005Metric; LCSC C23733
D1: YELLOW; LED_0805_2012Metric; LCSC C2296
D2: GREEN; LED_0805_2012Metric; LCSC C2297
D3, D4, D5, D6, D7, D8, D9, D10, D11, D12, D13, D14, D15, D16, D17, D18, D19, D20, D21, D22, D23, D24, D25: WHITE; LED_0805_2012Metric; LCSC C34499
F1: Fuse; Fuse_1206_3216Metric; LCSC C261957
J1: USB_C_Receptacle_USB2.0; USB_C_Receptacle_G-Switch_GT-USB-7010ASV; LCSC C2988369
J2: Conn_01x03_Socket; PinHeader_1x03_P2.54mm_Vertical; not fitted
J3: Conn_01x02; PinHeader_1x02_P2.54mm_Vertical; not fitted
J4: Conn_01x04; PinHeader_1x04_P2.54mm_Vertical; not fitted
J5: Conn_01x02; PinHeader_1x02_P2.54mm_Horizontal; LCSC C492410
L1: 3.3u; L_pol_2016; LCSC C42411119
MK1: LMA3722T421-OA5; LCSC C5373233
R1: 2K; R_0402_1005Metric; LCSC C4109
R2, R3, R4, R7, R9, R10, R11, R12, R13, R16, R17, R18, R19, R20, R21, R22, R23, R24, R25, R26, R27, R28, R29, R30, R31, R32, R33, R34: 1K; R_0402_1005Metric; LCSC C11702
R5, R6: 5.1K; R_0402_1005Metric; LCSC C25905
R8: 33; R_0402_1005Metric; LCSC C25105
R14, R15: 27; R_0402_1005Metric; LCSC C25100
SW1: POWER; SW_SPDT_PCM12; LCSC C431541
SW2, SW3, SW4, SW5, SW6, SW7, SW8, SW9, SW10, SW11: SW_Push; SW_Push_1P1T_XKB_TS-1187A; LCSC C318884
TP1, TP3: TestPoint; TestPoint_Pad_1.5x1.5mm
TP2, TP4: TestPoint; TestPoint_Pad_D1.5mm
U1: TLV1117LV-33; SOT-223-3_TabPin2; LCSC C15578
U2: USBLC6-2SC6; SOT-23-6; LCSC C2827654
U3: ME4054BM5G-N; TSOT-23-5; LCSC C478383
U4: RP2350_80QFN; RP2350-QFN-80-1EP_10x10_P0.4mm_EP3.4x3.4mm_ThermalVias; LCSC C42415655
U5: W25Q128JVS; SOIC-8_5.23x5.23mm_P1.27mm; LCSC C97521
X1: Simple_Addon_v2; Simple_Addon_v2-BADGE-2x3; LCSC C2935983
Y1: ABM8-272-T3; Crystal_SMD_3225-4Pin_3.2x2.5mm; LCSC C20625731

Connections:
+1V1: C8.1, C9.1, C11.1, C12.1, L1.1, U4.10 (DVDD), U4.32 (DVDD), U4.51 (DVDD), U4.65 (VREG_FB)
+3V3: C4.1, C5.1, C7.1, C13.1, C14.1, C15.1, C16.1, C17.1, C18.1, C19.1, C20.1, C21.1, C22.1, J4.2, MK1.2 (V_{DD}), R3.1, R8.1, TP3.1, U1.2 (VO), U4.5 (IOVDD), U4.15 (IOVDD), U4.24 (IOVDD), U4.29 (IOVDD), U4.41 (IOVDD), U4.50 (IOVDD), U4.59 (ADC_AVDD), U4.60 (IOVDD), U4.64 (VREG_VIN), U4.68 (USB_OTP_VDD), U4.69 (QSPI_IOVDD), U4.76 (IOVDD), U5.8 (VCC), X1.1 (VCC)
+BATT: C1.1, SW1.2 (B), U1.3 (VI)
/BADGE_BONUS: R34.1, U4.44 (GPIO35)
/BADGE_COMPLETE: R33.1, U4.43 (GPIO34)
/BUTTON_A: SW11.1, U4.16 (GPIO16)
/BUTTON_B: SW10.1, U4.17 (GPIO17)
/BUTTON_SELECT: SW9.1, U4.18 (GPIO18)
/BUTTON_START: SW8.1, U4.19 (GPIO19)
/DPAD_DOWN: SW7.1, U4.21 (GPIO21)
/DPAD_LEFT: SW5.1, U4.23 (GPIO23)
/DPAD_RIGHT: SW6.1, U4.20 (GPIO20)
/DPAD_UP: SW4.1, U4.22 (GPIO22)
/DTMF_BONUS: R23.1, U4.38 (GPIO30)
/DTMF_COMPLETE: R18.1, U4.39 (GPIO31)
/DTMF_MIC: MK1.1 (OUT), U4.49 (GPIO40_ADC0)
/GPIO8: U4.6 (GPIO8)
/GPIO9: U4.7 (GPIO9)
/GPIO10: U4.8 (GPIO10)
/GPIO11: U4.9 (GPIO11)
/GPIO12: U4.11 (GPIO12)
/GPIO13: U4.12 (GPIO13)
/GPIO14: U4.13 (GPIO14)
/GPIO15: U4.14 (GPIO15)
/HILO_COMPLETE: R31.1, U4.26 (GPIO25)
/HILO_HI: R29.1, U4.28 (GPIO27)
/HILO_LO: R32.1, U4.27 (GPIO26)
/I2C0_SCL: J4.3, U4.42 (GPIO33), X1.4 (SCL)
/I2C0_SDA: J4.4, U4.40 (GPIO32), X1.3 (SDA)
/KODE_COMPLETE: R16.1, U4.25 (GPIO24)
/QSPI_SCLK: U4.71 (QSPI_SCLK), U5.6 (CLK)
/QSPI_SD0: U4.72 (QSPI_SD0), U5.5 (DI(IO0))
/QSPI_SD1: U4.74 (QSPI_SD1), U5.2 (DO(IO1))
/QSPI_SD2: U4.73 (QSPI_SD2), U5.3 (IO2)
/QSPI_SD3: U4.70 (QSPI_SD3), U5.7 (IO3)
/QSPI_SS: R9.1, U4.75 (QSPI_SS), U5.1 (~CS)
/RPS_BONUS: R26.1, U4.58 (GPIO47_ADC7)
/RPS_COMPLETE: R21.1, U4.57 (GPIO46_ADC6)
/RPS_PAPER: R24.1, U4.56 (GPIO45_ADC5)
/RPS_ROCK: R19.1, U4.54 (GPIO43_ADC3)
/RPS_RX: J5.2, U4.53 (GPIO42_ADC2)
/RPS_SCISSORS: R27.1, U4.55 (GPIO44_ADC4)
/RPS_TX: J5.1, U4.52 (GPIO41_ADC1)
/RUN: SW3.2, U4.35 (RUN)
/SAO_GPIO1: U4.37 (GPIO29), X1.5 (GPIO1)
/SAO_GPIO2: U4.36 (GPIO28), X1.6 (GPIO2)
/SCORE_1: R10.1, U4.48 (GPIO39)
/SCORE_2: R11.1, U4.47 (GPIO38)
/SCORE_4: R12.1, U4.46 (GPIO37)
/SCORE_8: R13.1, U4.45 (GPIO36)
/SIMON_BONUS: R28.1, U4.80 (GPIO3)
/SIMON_COMPLETE: R22.1, U4.79 (GPIO2)
/SIMON_DOWN: R30.1, U4.3 (GPIO6)
/SIMON_LEFT: R25.1, U4.1 (GPIO4)
/SIMON_RIGHT: R20.1, U4.4 (GPIO7)
/SIMON_UP: R17.1, U4.2 (GPIO5)
/SWCLK: J2.1, U4.33 (SWCLK)
/SWD: J2.3, U4.34 (SWD)
/UART0_RX: J3.2, U4.78 (GPIO1)
/UART0_TX: J3.1, U4.77 (GPIO0)
/USB_D+: J1.A6 (D+), J1.B6 (D+), R14.1, U2.1 (I/O1), U2.6 (I/O1)
/USB_D-: J1.A7 (D-), J1.B7 (D-), R15.1, U2.3 (I/O2), U2.4 (I/O2)
/VREG_AVDD: C10.1, R8.2, U4.61 (VREG_AVDD)
/VREG_LX: L1.2, U4.63 (VREG_LX)
/XIN: C2.1, U4.30 (XIN), Y1.1
/XOUT: R4.1, U4.31 (XOUT)
/~USB_BOOT: R9.2, SW2.2
GND: BT2.2 (-), BT3.1, C1.2, C2.2, C3.2, C4.2, C5.2, C6.2, C7.2, C8.2, C9.2, C10.2, C11.2, C12.2, C13.2, C14.2, C15.2, C16.2, C17.2, C18.2, C19.2, C20.2, C21.2, C22.2, D2.1 (K), D3.1 (K), D4.1 (K), D5.1 (K), D6.1 (K), D7.1 (K), D8.1 (K), D9.1 (K), D10.1 (K), D11.1 (K), D12.1 (K), D13.1 (K), D14.1 (K), D15.1 (K), D16.1 (K), D17.1 (K), D18.1 (K), D19.1 (K), D20.1 (K), D21.1 (K), D22.1 (K), D23.1 (K), D24.1 (K), D25.1 (K), J1.A1 (GND), J1.A12 (GND), J1.B1 (GND), J1.B12 (GND), J2.2, J4.1, MK1.3 (GND), MK1.4 (GND), R1.2, R5.1, R6.2, R7.2, SW2.1, SW4.2, SW5.2, SW6.2, SW7.2, SW8.2, SW9.2, SW10.2, SW11.2, TP2.1, TP4.1, U1.1 (GND), U2.2 (GND), U3.2 (GND), U4.62 (VREG_PGND), U4.81 (GND), U5.4 (GND), X1.2 (GND), Y1.2, Y1.4
unnamed: BT1.1, BT2.1 (+), F1.2
unnamed: C3.1, R4.2, Y1.3
unnamed: D1.2 (A), R2.2
unnamed: D1.1 (K), U3.1 (~CHRG)
unnamed: D2.2 (A), R3.2
unnamed: D3.2 (A), R10.2
unnamed: D4.2 (A), R11.2
unnamed: D5.2 (A), R12.2
unnamed: D6.2 (A), R13.2
unnamed: D7.2 (A), R16.2
unnamed: D8.2 (A), R17.2
unnamed: D9.2 (A), R18.2
unnamed: D10.2 (A), R19.2
unnamed: D11.2 (A), R20.2
unnamed: D12.2 (A), R21.2
unnamed: D13.2 (A), R22.2
unnamed: D14.2 (A), R23.2
unnamed: D15.2 (A), R24.2
unnamed: D16.2 (A), R25.2
unnamed: D17.2 (A), R26.2
unnamed: D18.2 (A), R27.2
unnamed: D19.2 (A), R28.2
unnamed: D20.2 (A), R29.2
unnamed: D21.2 (A), R30.2
unnamed: D22.2 (A), R31.2
unnamed: D23.2 (A), R32.2
unnamed: D24.2 (A), R33.2
unnamed: D25.2 (A), R34.2
unnamed: J1.A5 (CC1), R6.1
unnamed: J1.B5 (CC2), R5.2
unnamed: R7.1, SW3.1
unnamed: F1.1, SW1.1 (A), U3.3 (BAT)
unnamed: R1.1, U3.5 (PROG)
unnamed: R15.2, U4.66 (USB_DM)
unnamed: R14.2, U4.67 (USB_DP)
VBUS: C6.1, J1.A4 (VBUS), J1.A9 (VBUS), J1.B4 (VBUS), J1.B9 (VBUS), R2.1, TP1.1, U2.5 (VBUS), U3.4 (V_{CC})

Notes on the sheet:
Primary Flash
USB-C
12MHz Crystal
UART
Buttons
Charge Controller
Test Pads
HiLo
Badge Complete LEDs
Simon
Display
Bulk decoupling capacitor. Place anywhere on board.
DTMF
Debug
Voltage Regulator
SAO
Kode
Note: Place C? close to U? pin 3, and C? to U? pin 2.
Make sure R5 and R6 are close to RP2350
Scoreboard
Rock Paper Scissors

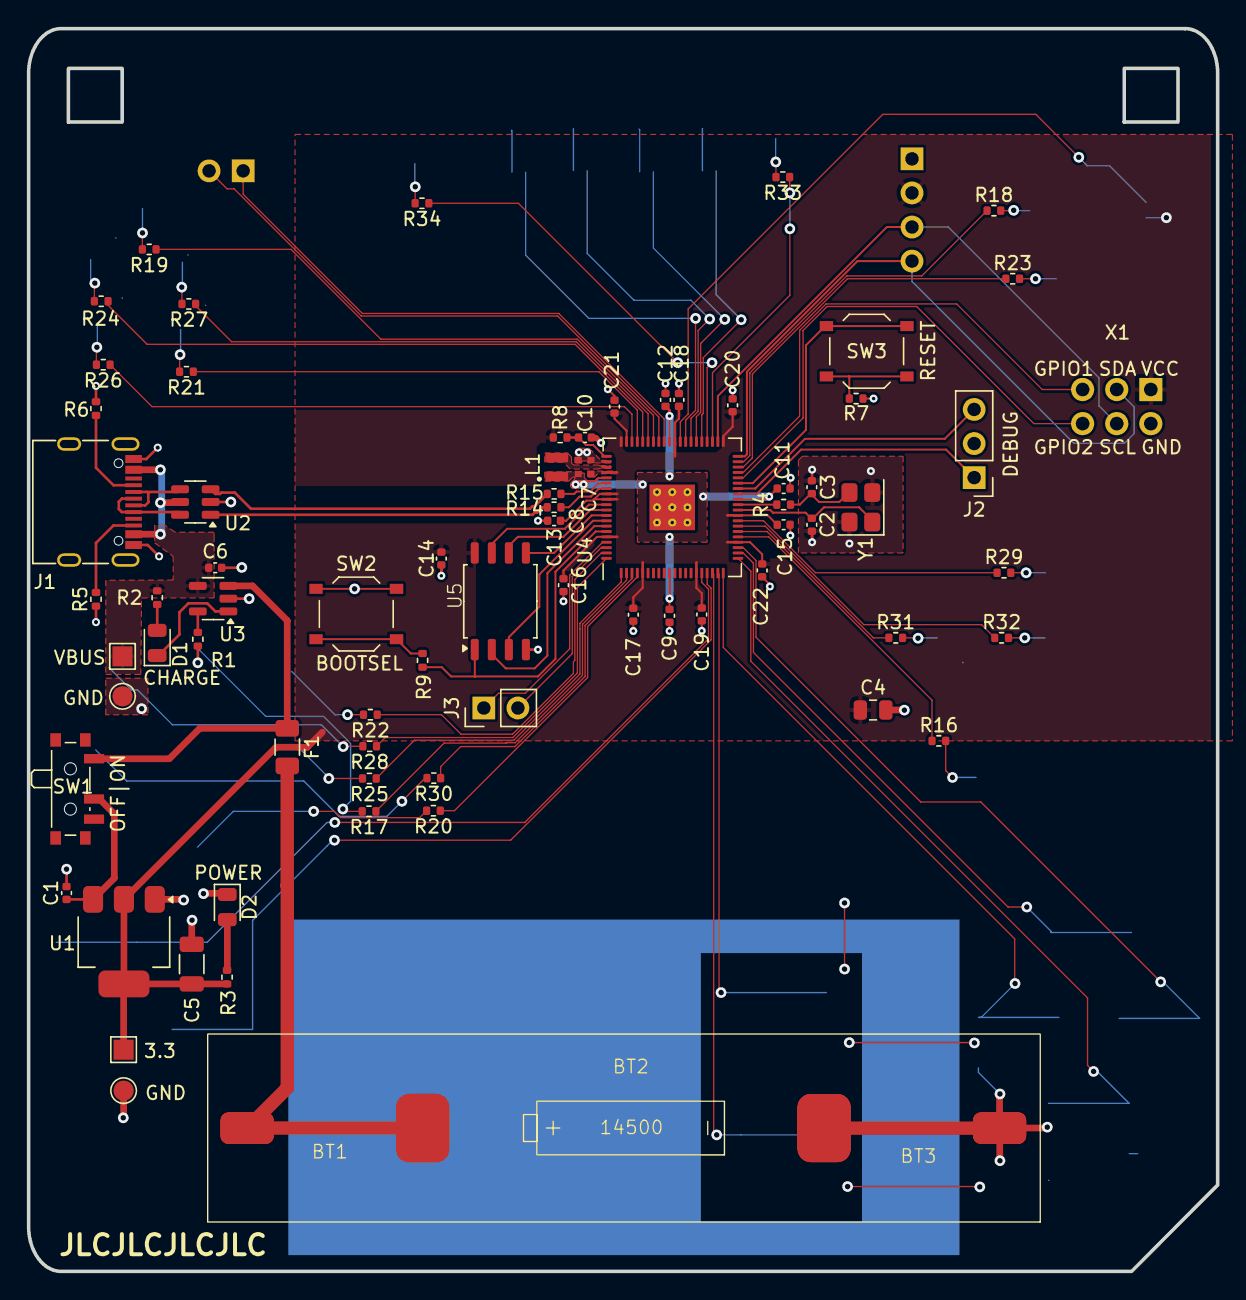
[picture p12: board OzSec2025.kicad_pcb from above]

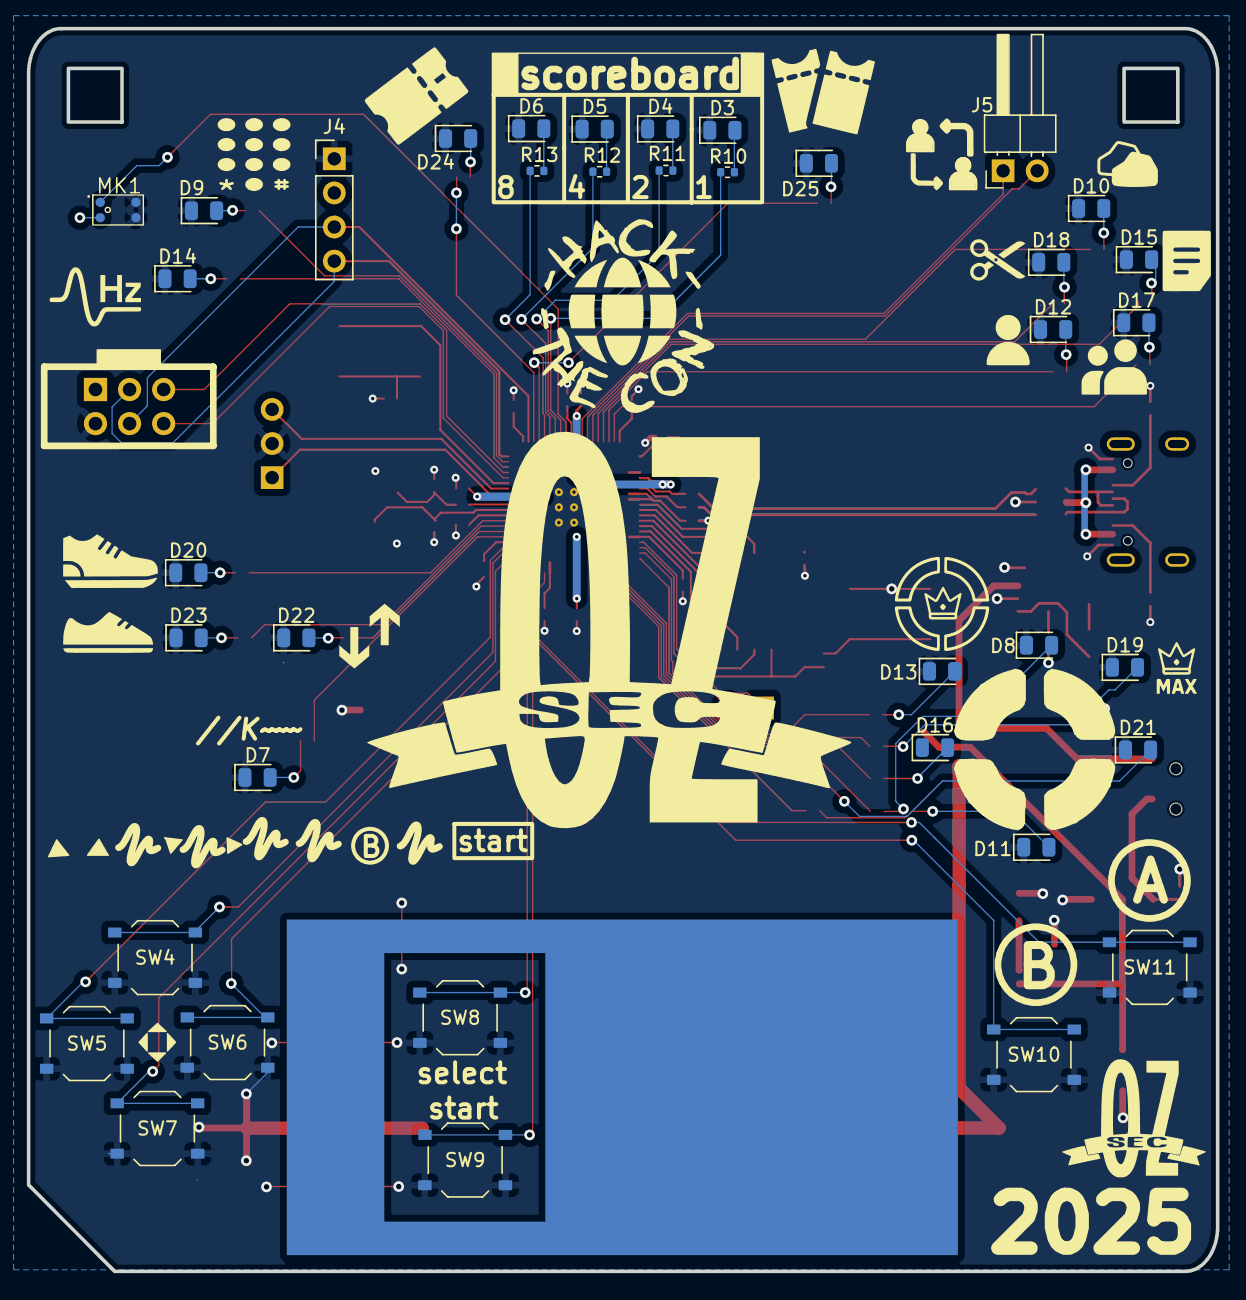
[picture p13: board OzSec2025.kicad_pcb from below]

Board: 2 copper layers, 88.6 x 92.6 mm, 114 parts (39 on the bottom side), 96 nets.

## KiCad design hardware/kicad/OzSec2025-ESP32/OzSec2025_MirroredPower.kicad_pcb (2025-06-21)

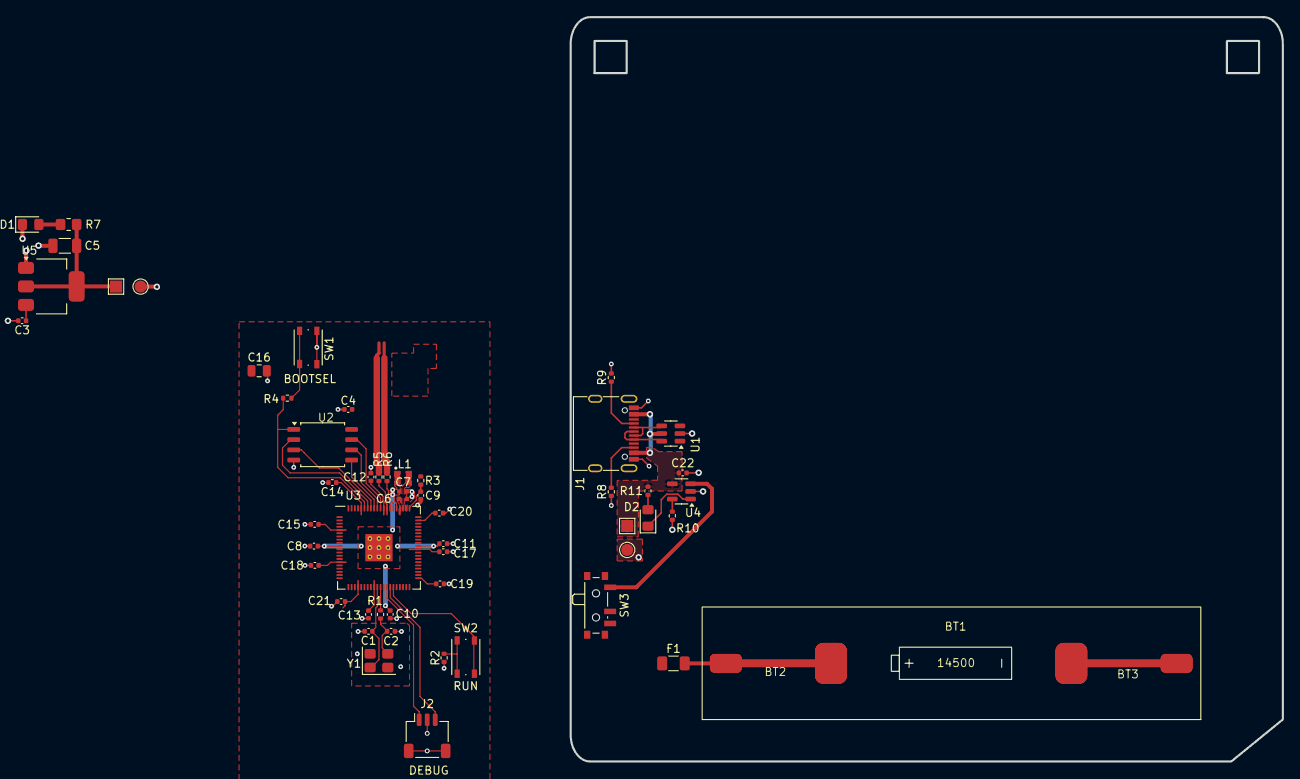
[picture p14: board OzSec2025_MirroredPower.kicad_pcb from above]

Board: 2 copper layers, 88.6 x 92.6 mm, 55 parts (0 on the bottom side), 34 nets.

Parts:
BT1: Battery; MY-AA-04
BT2: Battery_Clip_+; MY-AA-04_BT1A
BT3: Battery_Clip_-; MY-AA-04_BT1B
C1, C2: 15p; C_0402_1005Metric
C3: 0.1uF; C_0402_1005Metric
C4, C8, C11, C12, C13, C14, C15, C17, C18, C19, C20, C21: 100n; C_0402_1005Metric
C5: 100uF; C_1206_3216Metric
C6, C7: 4.7u; C_0402_1005Metric_small_pads
C9, C10: 4.7u; C_0402_1005Metric
C16: 10u; C_0805_2012Metric
C22: 1uF; C_0402_1005Metric
D1: POWER; LED_0805_2012Metric_Pad1.15x1.40mm_HandSolder
D2: CHARGING; LED_0805_2012Metric_Pad1.15x1.40mm_HandSolder
F1: Fuse; Fuse_1206_3216Metric
J1: USB_C_Receptacle_USB2.0; USB_C_Receptacle_G-Switch_GT-USB-7010ASV
J2: SM03B-SRSS-TB; JST_SH_SM03B-SRSS-TB_1x03-1MP_P1.00mm_Horizontal
L1: 3.3u; L_pol_2016
R1, R2, R4: 1k; R_0402_1005Metric
R3: 33; R_0402_1005Metric
R5, R6: 27; R_0402_1005Metric
R7: 1K; R_0805_2012Metric_Pad1.20x1.40mm_HandSolder
R8, R9: 5.1K; R_0402_1005Metric
R10: 2K; R_0402_1005Metric
R11: 1K; R_0402_1005Metric
SW1, SW2: SW_Push; SW_Push_1P1T_NO_Vertical_Wuerth_434133025816
SW3: POWER; SW_SPDT_PCM12
TP1, TP3: TestPoint; TestPoint_Pad_1.5x1.5mm
TP2, TP4: TestPoint; TestPoint_Pad_D1.5mm
U1: USBLC6-2SC6; SOT-23-6
U2: W25Q128JVS; SOIC-8_5.23x5.23mm_P1.27mm
U3: RP2350_80QFN; RP2350-QFN-80-1EP_10x10_P0.4mm_EP3.4x3.4mm_ThermalVias
U4: ME4054BM5G-N; TSOT-23-5
U5: TLV1117LV-33; SOT-223-3_TabPin2
Y1: ABM8-272-T3; Crystal_SMD_3225-4Pin_3.2x2.5mm

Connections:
+1V1: C7.1, C8.1, C10.1, C11.1, L1.1, U3.10 (DVDD), U3.32 (DVDD), U3.51 (DVDD), U3.65 (VREG_FB)
+3.3V: C5.1, R7.1, TP3.1, U5.2 (VO)
+3V3: C4.1, C6.1, C12.1, C13.1, C14.1, C15.1, C16.1, C17.1, C18.1, C19.1, C20.1, C21.1, R3.1, U2.8 (VCC), U3.5 (IOVDD), U3.15 (IOVDD), U3.24 (IOVDD), U3.29 (IOVDD), U3.41 (IOVDD), U3.50 (IOVDD), U3.59 (ADC_AVDD), U3.60 (IOVDD), U3.64 (VREG_VIN), U3.68 (USB_OTP_VDD), U3.69 (QSPI_IOVDD), U3.76 (IOVDD)
+BATT: C3.1, SW3.2 (B), U5.3 (VI)
/QSPI_SCLK: U2.6 (CLK), U3.71 (QSPI_SCLK)
/QSPI_SD0: U2.5 (DI(IO0)), U3.72 (QSPI_SD0)
/QSPI_SD1: U2.2 (DO(IO1)), U3.74 (QSPI_SD1)
/QSPI_SD2: U2.3 (IO2), U3.73 (QSPI_SD2)
/QSPI_SD3: U2.7 (IO3), U3.70 (QSPI_SD3)
/QSPI_SS: R4.1, U2.1 (~CS), U3.75 (QSPI_SS)
/RUN: SW2.2, U3.35 (RUN)
/SWCLK: J2.1, U3.33 (SWCLK)
/SWD: J2.3, U3.34 (SWD)
/USB_D+: J1.A6 (D+), J1.B6 (D+), R5.1, U1.1 (I/O1), U1.6 (I/O1)
/USB_D-: J1.A7 (D-), J1.B7 (D-), R6.1, U1.3 (I/O2), U1.4 (I/O2)
/VREG_AVDD: C9.1, R3.2, U3.61 (VREG_AVDD)
/VREG_LX: L1.2, U3.63 (VREG_LX)
/XIN: C1.1, U3.30 (XIN), Y1.1
/XOUT: R1.1, U3.31 (XOUT)
/~USB_BOOT: R4.2, SW1.2
GND: BT1.2 (-), BT3.1, C1.2, C2.2, C3.2, C4.2, C5.2, C6.2, C7.2, C8.2, C9.2, C10.2, C11.2, C12.2, C13.2, C14.2, C15.2, C16.2, C17.2, C18.2, C19.2, C20.2, C21.2, C22.2, D1.1 (K), J1.A1 (GND), J1.A12 (GND), J1.B1 (GND), J1.B12 (GND), J2.2, J2.MP (MountPin), R2.2, R8.1, R9.2, R10.2, SW1.1, TP2.1, TP4.1, U1.2 (GND), U2.4 (GND), U3.62 (VREG_PGND), U3.81 (GND), U4.2 (GND), U5.1 (GND), Y1.2, Y1.4
unnamed: BT1.1 (+), BT2.1, F1.2
unnamed: C2.1, R1.2, Y1.3
unnamed: D1.2 (A), R7.2
unnamed: D2.2 (A), R11.2
unnamed: D2.1 (K), U4.1 (~CHRG)
unnamed: J1.A5 (CC1), R9.1
unnamed: J1.B5 (CC2), R8.2
unnamed: R2.1, SW2.1
unnamed: F1.1, SW3.1 (A), U4.3 (BAT)
unnamed: R6.2, U3.66 (USB_DM)
unnamed: R5.2, U3.67 (USB_DP)
unnamed: R10.1, U4.5 (PROG)
VBUS: C22.1, J1.A4 (VBUS), J1.A9 (VBUS), J1.B4 (VBUS), J1.B9 (VBUS), R11.1, TP1.1, U1.5 (VBUS), U4.4 (V_{CC})

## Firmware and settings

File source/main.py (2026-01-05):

"""
CRASHANDBURN Main.py

This is the main script for the CRASHANDBURN badge firmware. 

By default this script will blink LED's, and wait for input to
select a different game/mode.


"""

from machine import Timer
import time
import random

import scoreboard
import button
import led
from games.hilo import HiLoGame
from games.rps import RPSGame
from games.dtmf import DtmfGame
from games.kode import KodeGame
# from games.light import LightGame
# from games.left_right import LeftRightGame
# from games.dtmf import DtmfGame


class GameSelector:
    def __init__(self):
        self.games = [
            {"name": "HiLo", "led": led.hilo_complete, "class": HiLoGame},
            {"name": "DTMF", "led": led.dtmf_complete, "class": DtmfGame},
            {"name": "Kode", "led": led.kode_complete, "class": KodeGame},
            {"name": "RPS", "led": led.rps_complete, "class": RPSGame}  # ,
            # {"name": "Test", "led": led.badge_complete, "class": TestGame}
        ]
        self.current_index = 0
        self.current_game = None
        print(f"Initialized GameSelector with {len(self.games)} games.")

    def next_game(self):
        self.current_index = (self.current_index + 1) % len(self.games)
        print(
            f"Selected next game: [{self.current_index}] {self.games[self.current_index]['name']}")
        self.update_leds()

    def update_leds(self):
        for i, game in enumerate(self.games):
            if i == self.current_index:
                print(f"Selected game [{i}]: {game['name']}")
                game["led"].flash()
                scoreboard.scoreboard.show_score(game["name"])
            else:
                game["led"].off()

    def run_current_game(self):
        print(
            f"Running game [{self.current_index}] {self.games[self.current_index]['name']}")
        self.current_game = self.games[self.current_index]["class"]()
        self.current_game.run()


def callback_next_game(pin, pressed, duration):
    global game_selector
    if pressed:
        print("Next game button pressed.")
        stop_blink_timer()
        game_selector.next_game()


def callback_start_game(pin, pressed, duration):
    global game_selector
    if pressed:
        print("Start game button pressed.")
        stop_blink_timer()
        game_selector.run_current_game()


def callback_toggle_led_mode(pin, pressed, duration):
    """
    Callback to toggle the LED state.
    """
    global blinky_mode

    if pressed:
        if blinky_mode:
            stop_blink_timer()
        else:
            start_blink_timer()


def start_blink_timer():
    global idle_timer, blinky_mode

    idle_timer = Timer(2)
    idle_timer.init(period=500, mode=Timer.PERIODIC, callback=blink_random)
    blinky_mode = True


def stop_blink_timer():
    global idle_timer, blinky_mode

    if idle_timer is not None:
        idle_timer.deinit()
    blinky_mode = False
    led.clear()


def register_callbacks():
    print("Registering button callbacks...")
    button.start.callback = callback_start_game  # type: ignore
    button.select.callback = callback_next_game  # type: ignore
    button.a.callback = callback_toggle_led_mode  # type: ignore
    button.b.callback = callback_toggle_led_mode  # type: ignore


def blink_random(run=True):
    """
    Randomly selects an LED to blink
    """
    global led, blinky_mode
    if run:
        blinky_mode = True
        # Select a random LED
        leds = led.get_all_leds()
        selected_led = random.choice(leds)
        selected_led.toggle(fade=True)
    else:
        blinky_mode = False
        led.clear()


print("Starting CRASHANDBURN")
game_selector = GameSelector()
idle_timer = None
blinky_mode = False


# Clear buttons and leds
button.clear()
led.clear()

# Register our button callbacks
register_callbacks()

# Start the idle blink
start_blink_timer()

while True:
    if game_selector.current_game is not None:
        if game_selector.current_game.is_running == False:
            game_selector.current_game = None  # Clear the current game
            button.clear()  # Clear button callbacks
            led.clear()  # Clear LEDs
            register_callbacks()  # Re-register the callbacks

    time.sleep(0.1)
    pass

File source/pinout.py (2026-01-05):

"""
Pinout configuration

Defines pins for prototyping and production. Prototype versions used a Pico 2
which does not have enough GPIO available for all games.

Prototype_1: Missing I2C, SAO GPIO, Simon, and DTMF games
Prototype_2: Missing I2C, SAO GPIO, HiLo and RPS game.
Production: All pins available.
"""
from machine import Pin

pinout_type = "production"

print(f"Using pinout type: {pinout_type}")


if pinout_type == "production":
    # Controller inputs
    pin_button_a = 12
    pin_button_b = 13
    pin_button_select = 14
    pin_button_start = 21
    pin_dpad_right = 47
    pin_dpad_down = 48
    pin_dpad_up = 38
    pin_dpad_left = 45

    # Scoreboard
    pin_score_eights = 15
    pin_score_fours = 7
    pin_score_twos = 6
    pin_score_ones = 5

    # Badge/Raffle LEDs
    pin_badge_complete = 2
    pin_badge_bonus = 4

    # Game LEDs
    pin_simon_complete = 46
    pin_simon_left = 11
    pin_simon_up = 3
    pin_simon_down = 10
    pin_simon_right = 9

    pin_kode_complete = 39

    pin_hilo_complete = 40
    pin_hilo_lo = 41
    pin_hilo_hi = 42

    pin_dtmf_bonus = 44
    pin_dtmf_complete = 43
    pin_dtmf_mic = 1

    pin_rps_rock = 16
    pin_rps_scissors = 18
    pin_rps_paper = 17
    pin_rps_complete = 8

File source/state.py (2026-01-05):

# Tracks game state, and completed status of each game

import machine
from machine import Pin

import led


class GameState:
    def __init__(self):
        self.completed_games = {
            "DTMF": False,
            "HiLo": False,
            "Kode": False,
            "Simon": False,
            "RPS": False
        }

    def complete(self, game_name):
        if game_name in self.completed_games:
            self.completed_games[game_name] = True
            print(f"Game {game_name} marked as completed.")
        else:
            print(f"Game {game_name} not found in game state.")

    def is_completed(self, game_name):
        return self.completed_games.get(game_name, False)

    def reset(self, game_name):
        if game_name in self.completed_games:
            self.completed_games[game_name] = False
            print(f"Game {game_name} has been reset to not completed.")
        else:
            print(f"Game {game_name} not found in game state.")


gamestate = GameState()

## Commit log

2025-02-07 Add Pico 2 pinout for reference.
2025-02-08 WIP for PIN's
2025-02-09 Breadboard config for buttons and leds.
2025-02-15 Moved DebouncedInput to button.py and added clear function.
2025-04-19 Updated gitignore with kicad stuff
2025-04-19 Initial work on pcb routing
    [ozsec2025.kicad_pcb, ozsec2025.kicad_sch]
2025-04-19 Update kicad libraries and initial work on routing.
2025-04-19 Update footprints
    [ozsec2025.kicad_sch]
2025-04-19 Clean slate on PCB.
    [ozsec2025.kicad_pcb]
2025-06-21 Removed outdated kicad files, and added some new ones.
    [ozsec2025.kicad_pcb, ozsec2025.kicad_sch]
2025-06-21 Added kicad files.
    [OzSec2025.kicad_pcb, OzSec2025.kicad_sch, OzSec2025_MirroredPower.kicad_pcb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]
2025-06-22 Blink and ability to pause/resume timers
2025-06-23 Added pinout definitions to support prototype testing with limited gpio
2025-06-24 Added brightness memory for PWM.
2025-06-24 Added debug prints.
2025-06-24 Updated games and added idle led mode toggle.
2025-06-26 Idle blinky and some fixes.
    [button.py, led.py, main.py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]
2026-01-05 Added fabrication files for v1.2
    [OzSec2025v1.1-S3_bom.csv, OzSec2025v1.2-S3_bom.csv, OzSec2025v1.2-S3_designators.csv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]
2026-01-05 Added esp32 firmware
2026-01-05 Updated kicad files
    [OzSec2025-ESP32.kicad_pcb, OzSec2025-ESP32.kicad_sch, OzSec2025_MirroredPower.kicad_pcb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]
2026-01-05 ESP32 updates, functional blinky
